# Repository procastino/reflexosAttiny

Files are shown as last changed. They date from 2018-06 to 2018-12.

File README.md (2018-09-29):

# reflexosAttiny
What can you do with three leds and a button? This is a very unflexible development board, where you must stretch your imagination to take some utility out of it. It has an attiny, the pushbutton and three leds. I left one pin free and accesible, because I'm a twisted guy with some goodness inside.
The real point of this was learning to design a simple board with KiCad and give some use to a bunch of AtTinys that I had laying around. Now I think it has some interest, for the right kind of people...
## Board
Develped in Kicad 4 (I'll upgrade if I beat my determined lazyness), it is surely not correct from a technical point of view, but it seems to work well.
## BOM
* 1 x AtTiny 85 - 20PU
* 1 x pushbutton 6 mm
* 3 x leds 3 mm
* 3 x 470 ohm resistors (depending on the leds, may need different value)
* 1 x 10Kohm resistor
* 12 right angle male pin headers
* 1 x cr2032 battery holder
* 1 x switch SK12D07V-G3

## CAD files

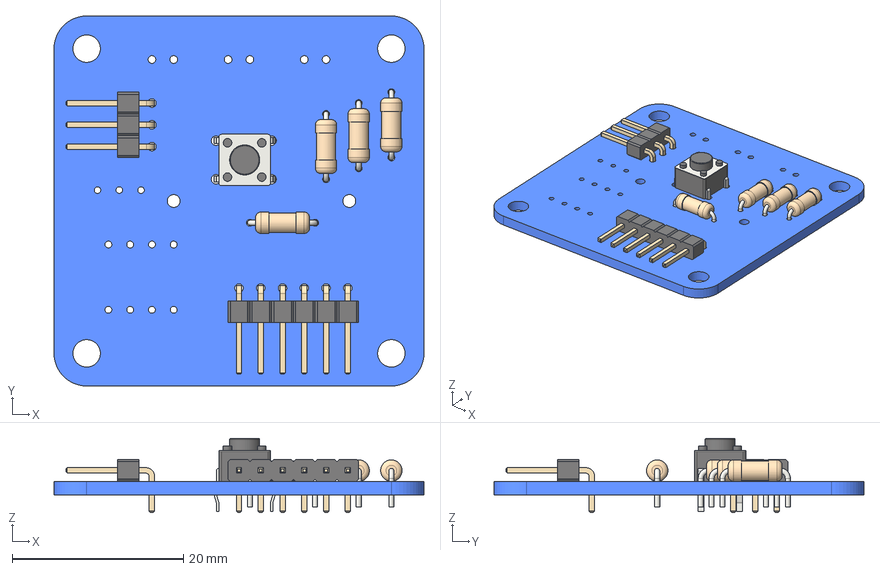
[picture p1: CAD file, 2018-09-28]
boardAttinyReflexos/attinyReflexos.step
43.2 x 43.2 x 8.64 mm
Pcb
Pin_Header_Angled_1x06_Pitch254mm_
Pin_Header_Angled_1x03_Pitch254mm_
R_Axial_DIN0207_L63mm_D25mm_P762mm_Horizontal_
R_Axial_DIN0207_L63mm_D25mm_P762mm_Horizontal_001
R_Axial_DIN0207_L63mm_D25mm_P762mm_Horizontal_002
R_Axial_DIN0207_L63mm_D25mm_P762mm_Horizontal_003
SW_PUSH_6mm_h5mm_

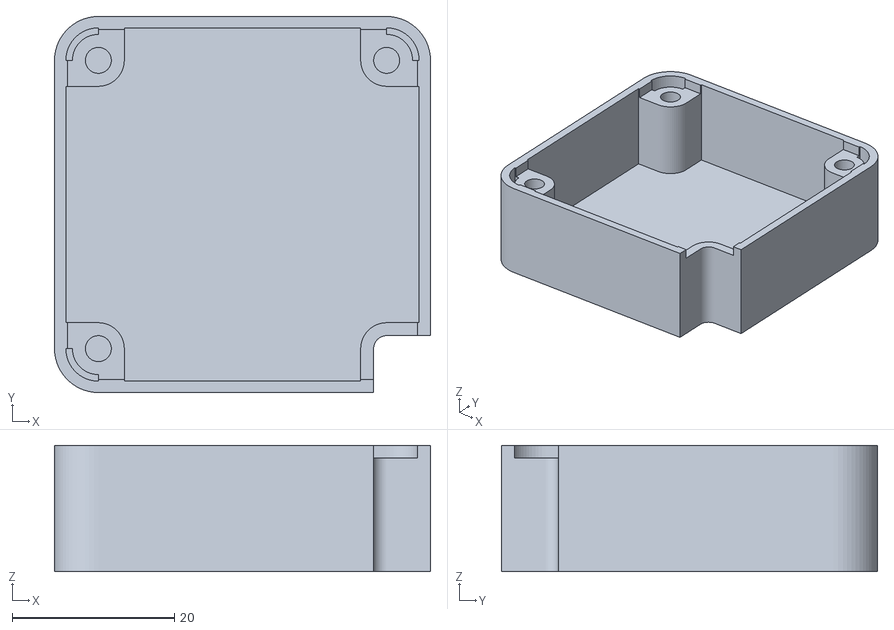
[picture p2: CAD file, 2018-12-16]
bottom.stl
46.4 x 46.4 x 15.6

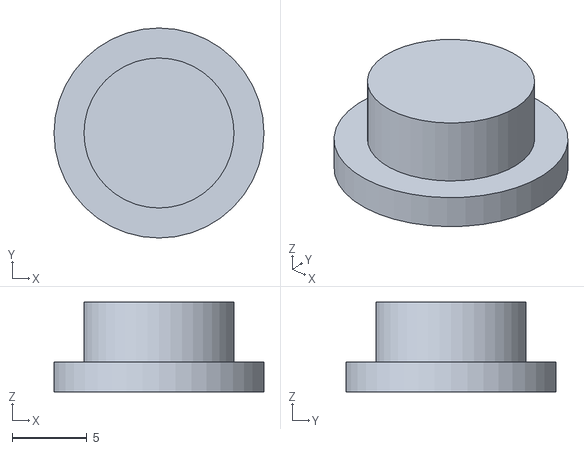
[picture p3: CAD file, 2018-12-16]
button2_6.stl
14.0 x 14.0 x 6.00

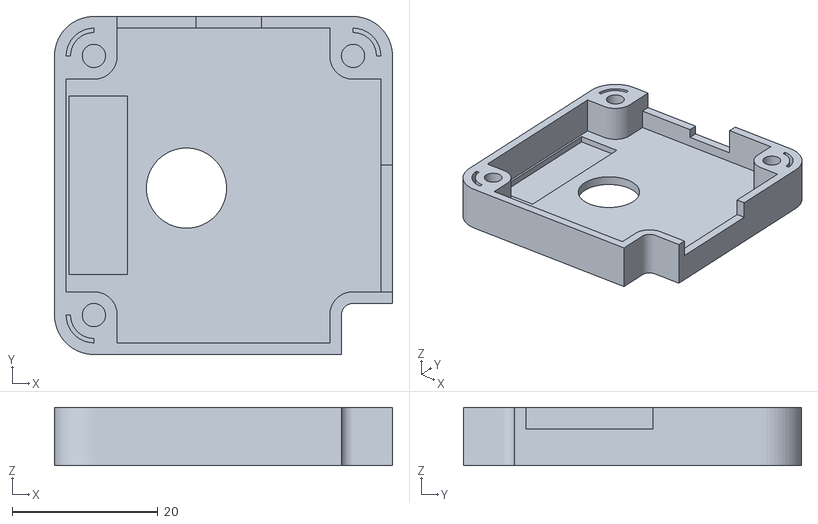
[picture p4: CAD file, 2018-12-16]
superior.stl
46.4 x 46.4 x 8.00

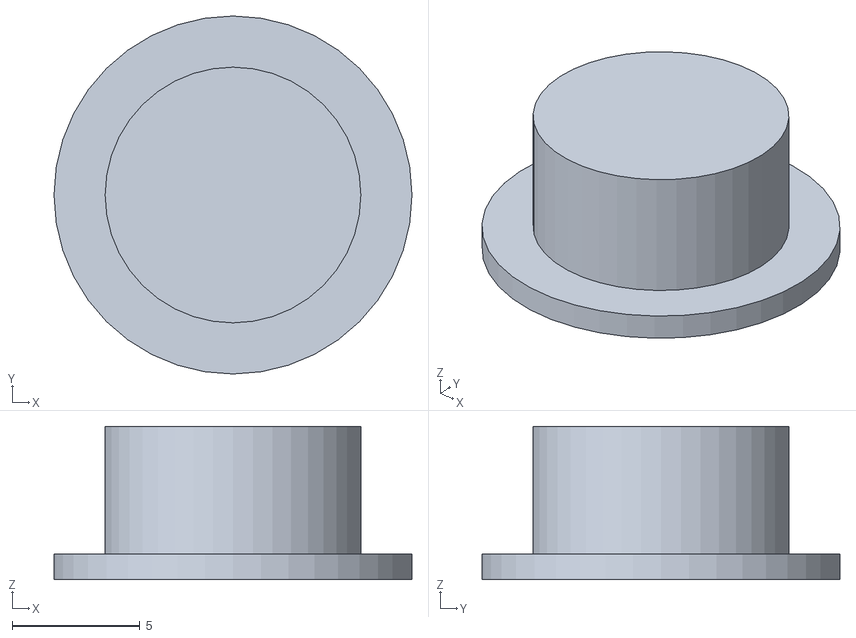
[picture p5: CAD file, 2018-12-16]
button1_6.stl
14.0 x 14.0 x 6.00

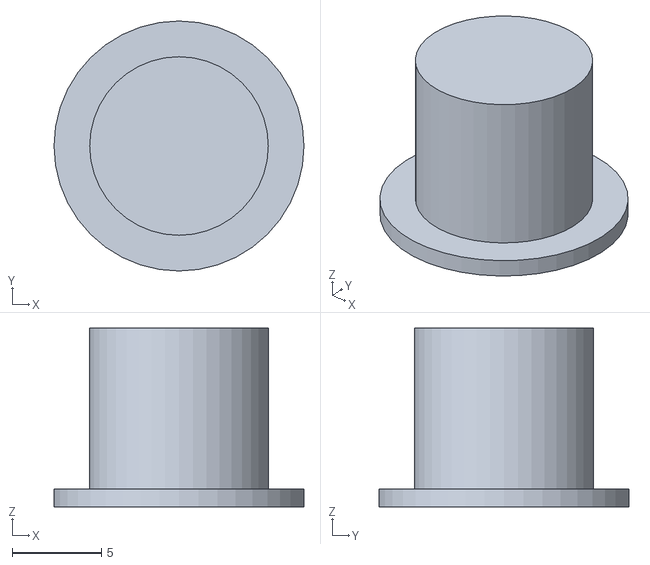
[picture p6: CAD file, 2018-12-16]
button1_10.stl
14.0 x 14.0 x 10.0

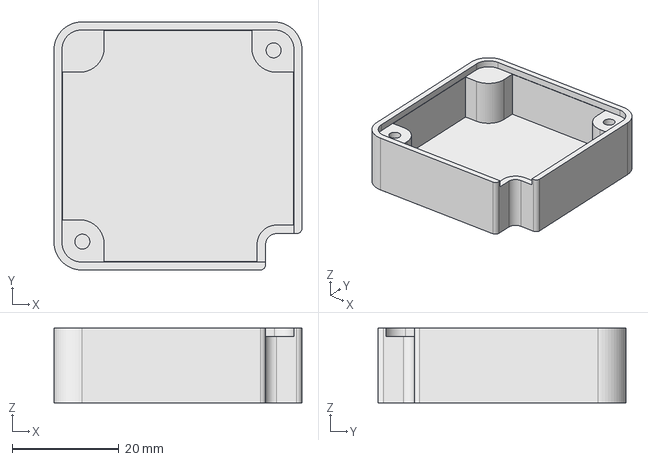
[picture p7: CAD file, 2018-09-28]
caixaPrimitivasSuperior.fcstd
46.4 x 46.4 x 14.0 mm

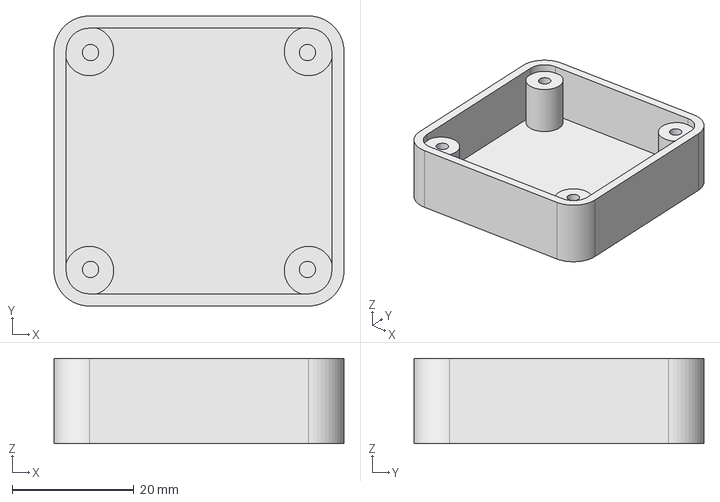
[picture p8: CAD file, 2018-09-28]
caixa.fcstd
47.6 x 47.6 x 14.0 mm

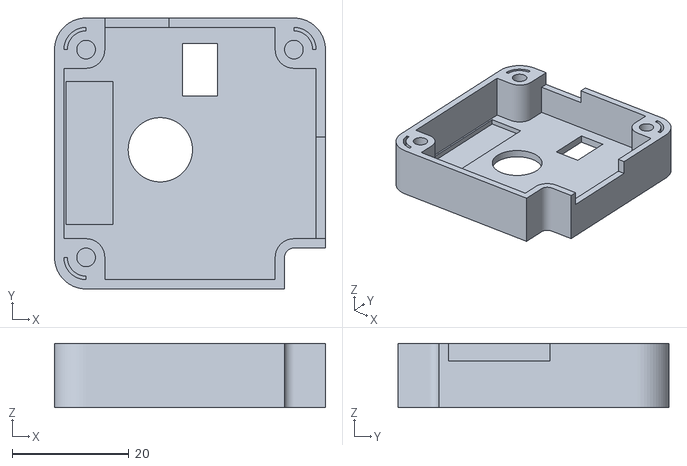
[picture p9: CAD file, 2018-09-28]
tapaSuperior.stl
46.4 x 46.4 x 11.0

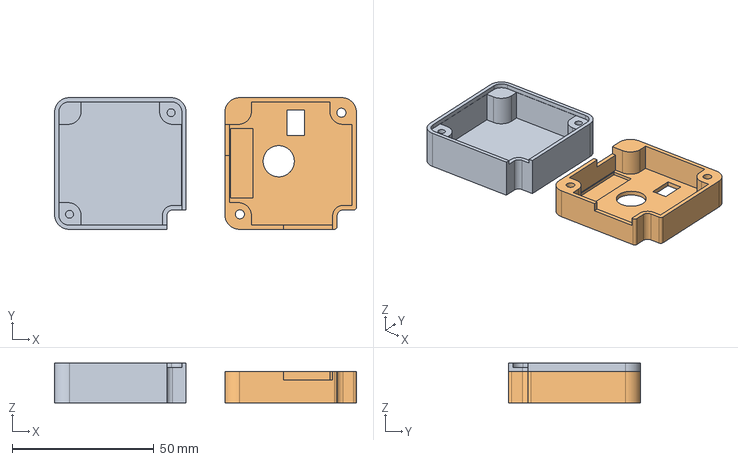
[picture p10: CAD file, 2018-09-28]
caixaPrimitivas.fcstd
106.4 x 46.4 x 14.0 mm
superior

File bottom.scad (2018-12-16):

$fn=60;
//distance between the holes of the pcb
holeDistance=35.56;
//tolerance for PCB carve, since the PDB doesn't fit well (quite a dirty fix)
tolerancePcb=0.2;
//thickness of the walls
thickness=1.6;
//distance between hole centers and pcb edge
holeToPcb=3.81;
//distance between hole centers and wall exterior
holeToExt=holeToPcb+thickness;
//radius of PCB holes
holeRadius=1.6;
//height of the whole bottom, from floor to top
height=14+thickness;

module exterior(){
    difference(){
        hull(){
        translate([holeToExt,holeToExt,0]) cylinder(r=holeToExt,h=height);
        translate([holeToExt,holeToExt+holeDistance,0]) cylinder(r=holeToExt,h=height);
        translate([holeToExt+holeDistance,holeToExt,0]) cylinder(r=holeToExt,h=height);
        translate([holeToExt+holeDistance,holeToExt+holeDistance,0]) cylinder(r=holeToExt,h=height);
        }
        translate ([holeToExt+holeDistance,holeToExt,0]) cornerCarve();
    }
}
module carve(){
    difference(){
  hull(){
    translate([holeToExt,holeToExt,0]) cylinder(r=holeToPcb+tolerancePcb,h=height);
   translate([holeToExt,holeToExt+holeDistance,0]) cylinder(r=holeToPcb+tolerancePcb,h=height);
   translate([holeToExt+holeDistance,holeToExt,0]) cylinder(r=holeToPcb+tolerancePcb,h=height);
   translate([holeToExt+holeDistance,holeToExt+holeDistance,0]) cylinder(r=holeToPcb+tolerancePcb,h=height);
    }
    translate ([holeToExt+holeDistance,holeToExt,0]) cornerCarveInt();
    }
}

//carving the pcb hole   
module pcbCarve(){
    hull(){
    translate([holeToExt,holeToExt,0]) cylinder(r=holeToPcb,h=height);
   translate([holeToExt,holeToExt+holeDistance,0]) cylinder(r=holeToPcb,h=height);
   translate([holeToExt+holeDistance,holeToExt,0]) cylinder(r=holeToPcb,h=height);
   translate([holeToExt+holeDistance,holeToExt+holeDistance,0]) cylinder(r=holeToPcb,h=height);
    }
  }
  
module support(){
difference(){
    union(){
        cylinder(r=holeRadius+thickness,h=height);
        translate([-holeToExt,0,0]) cube([holeToExt,holeRadius+thickness,height]);
         translate([0,-holeToExt,0]) cube([holeRadius+thickness,holeToExt,height]);
    }
translate([0,0,thickness])cylinder(r=holeRadius,h=height);
}
}
module cornerCarve() {
cylinder(r=holeRadius,h=height);
cube([holeToExt,holeRadius,height]);
translate([-holeRadius,-holeToExt-1,0]) cube([holeRadius+holeToExt,holeToExt+1,height]);
}
module cornerCarveInt() {
cylinder(r=holeRadius+thickness,h=height);
cube([holeToExt+thickness,holeRadius+thickness,height]);
translate([-(holeRadius+thickness),-(holeToExt+thickness+1),0]) cube([holeRadius+holeToExt+thickness,holeToExt+thickness+1,height]);
}
//we make the lid in here
difference(){
union(){
difference() {
    exterior();
    translate ([0,0,thickness]) carve();
    }
    
    translate([holeToExt,holeToExt,0]) support();
    translate([holeToExt,holeToExt+holeDistance,0])  rotate([0,0,-90]) support();
    translate([holeToExt+holeDistance,holeToExt+holeDistance,0]) rotate([0,0,180]) support();
}
 translate ([0,0,height-thickness]) pcbCarve();
}

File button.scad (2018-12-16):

$fn=40;
cylinder(r=7,h=1);
cylinder(r=5,h=10);

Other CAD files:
caixaInferiorPrimitivas.stl
caixaInferior.stl
superior.scad
boardAttinyReflexos/attinyReflexos.FCStd

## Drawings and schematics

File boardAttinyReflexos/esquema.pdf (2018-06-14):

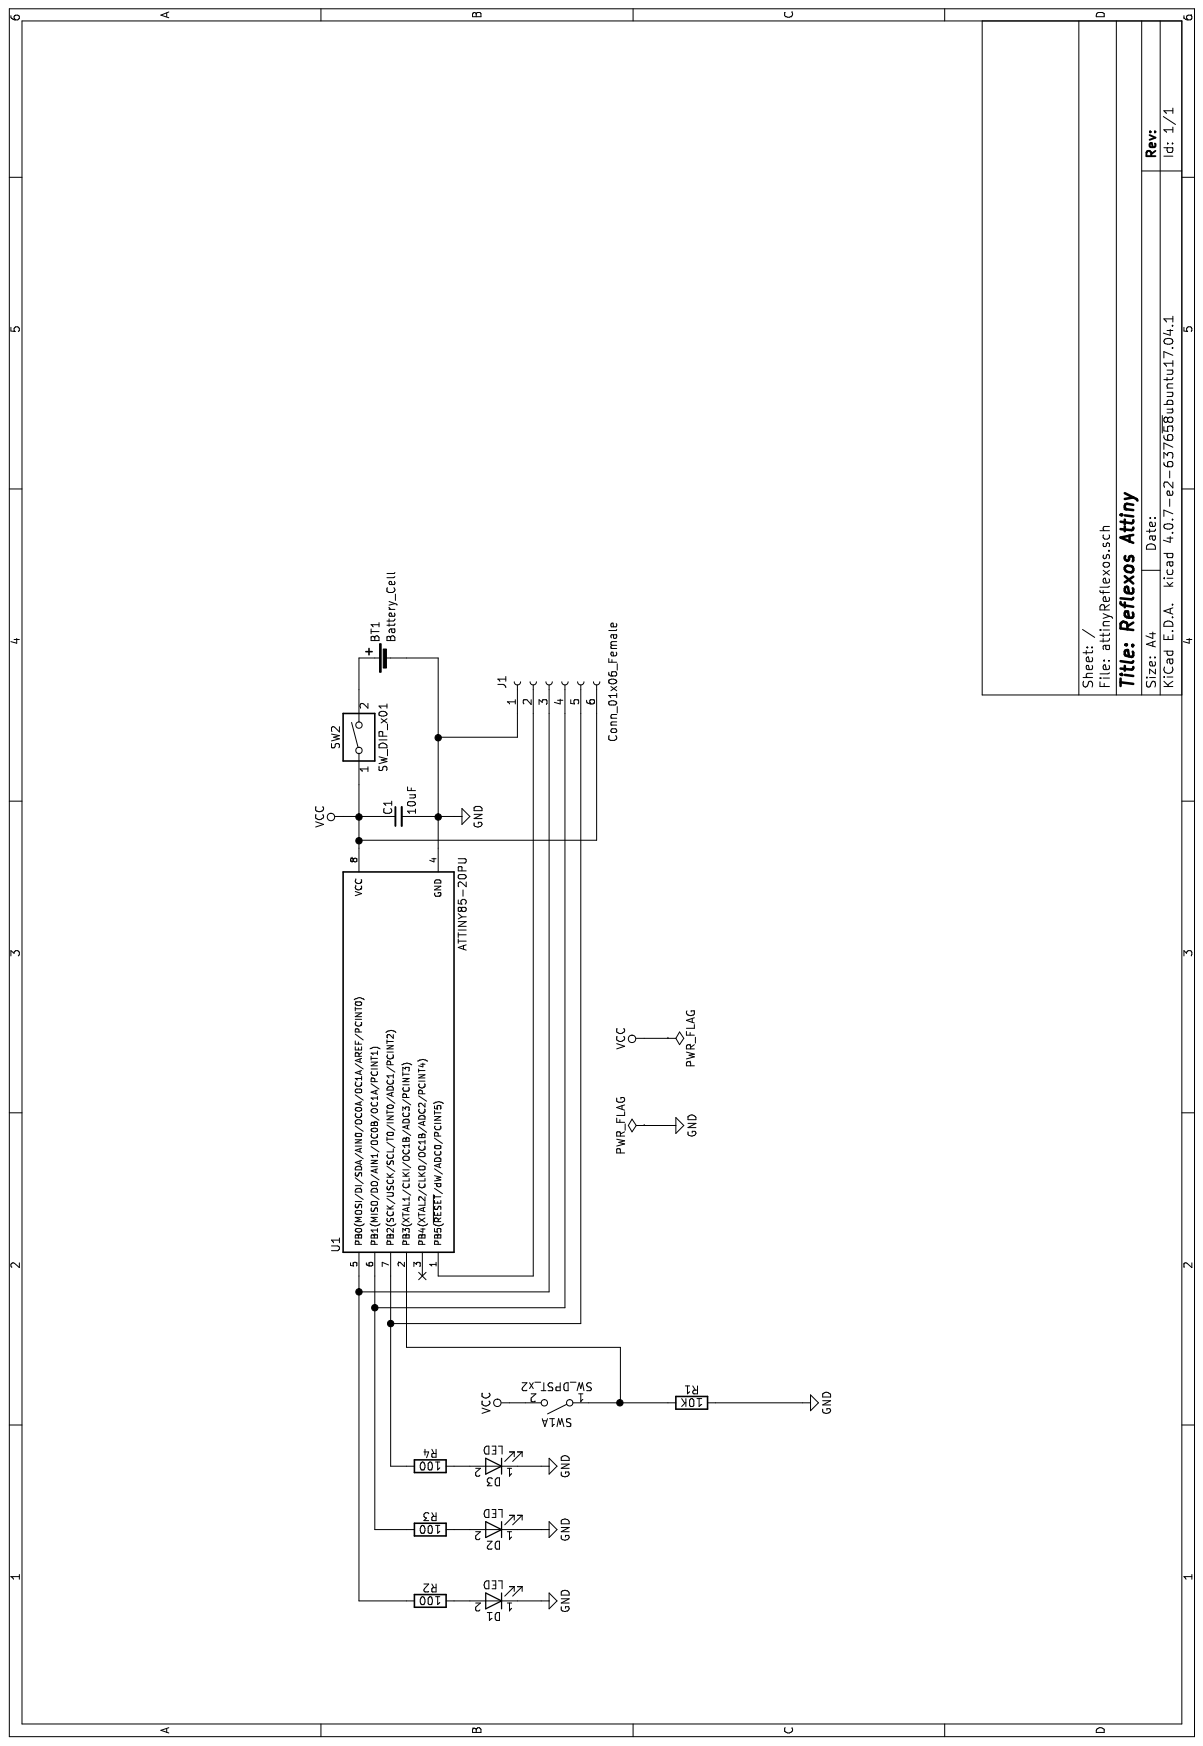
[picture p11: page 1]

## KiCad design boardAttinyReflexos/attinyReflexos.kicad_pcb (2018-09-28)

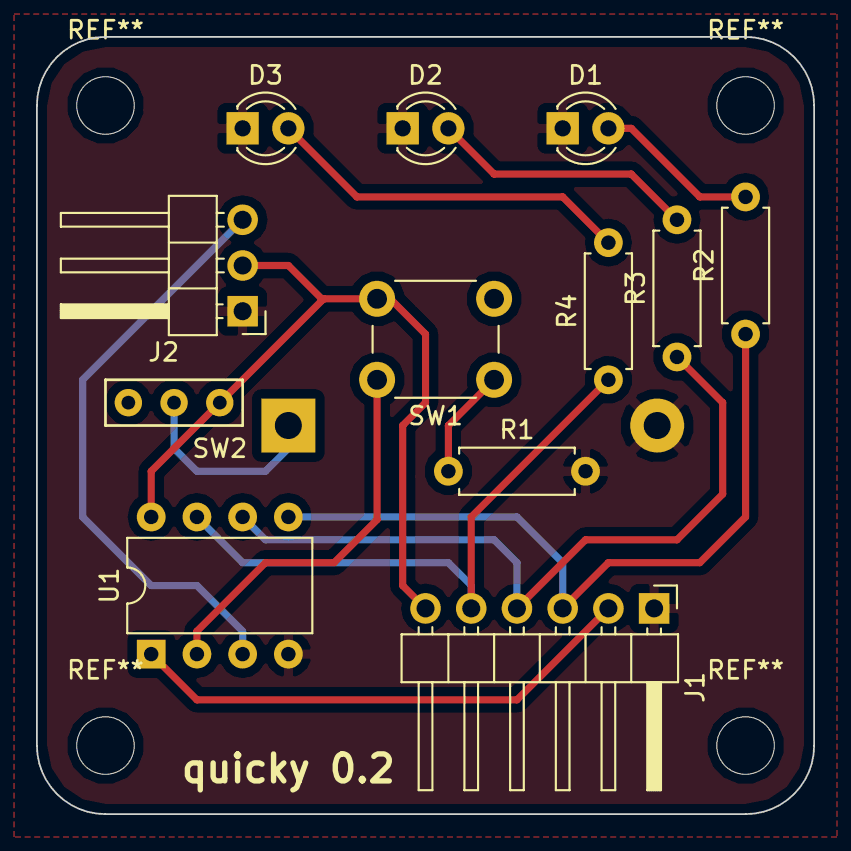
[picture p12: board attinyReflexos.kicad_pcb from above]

Board: 2 copper layers, 43.2 x 43.2 mm, 13 parts (1 on the bottom side), 12 nets.

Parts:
BT1: Battery_Cell; Keystone_103_1x20mm-CoinCell
D1, D2, D3: LED; LED_D3.0mm
J1: Conn_01x06_Female; Pin_Header_Angled_1x06_Pitch2.54mm
J2: Conn_01x03_Female; Pin_Header_Angled_1x03_Pitch2.54mm
R1: 10K; R_Axial_DIN0207_L6.3mm_D2.5mm_P7.62mm_Horizontal
R2, R3, R4: 100; R_Axial_DIN0207_L6.3mm_D2.5mm_P7.62mm_Horizontal
SW1: SW_DPST_x2; SW_PUSH_6mm_H5mm
SW2: SW_DIP_x01; switchSlide
U1: ATTINY85-20PU; DIP-8_W7.62mm

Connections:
GND: BT1.2, D1.1, D2.1, D3.1, J1.1, J2.1, R1.2, U1.4
unnamed: BT1.1, SW2.2
unnamed: D1.2, R2.2
unnamed: D2.2, R3.2
unnamed: D3.2, R4.2
unnamed: J1.2, U1.1
unnamed: J1.3, R2.1, U1.5
unnamed: J1.4, R3.1, U1.6
unnamed: J1.5, R4.1, U1.7
unnamed: J2.3, U1.3
unnamed: R1.1, SW1.1, U1.2
VCC: J1.6, J2.2, SW1.2, SW2.1, U1.8

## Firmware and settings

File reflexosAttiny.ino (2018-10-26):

/*Xogo de reflexos, debes pulsar o botón cando se acenda o led do medio, se acertas subirás un nivel, se fallas perderás.*/

//definimos os pines onde van os leds, boton e buzzer
//version 0.2    
    int led1=2;
    int led2=1;
    int led3=0;
    int boton=3;

//// version 0.1    
//    int led1=1;
//    int led2=2;
//    int led3=3;
//    int boton=0;

//// arduino UNO   
//    int led1=8;
//    int led2=9;
//    int led3=10;
//    int boton=7;

//definimos as variables que necesitaremos para ter conta do tempo
    long tempoActual = 0;
//este seria o tempo de espera co que arranca o xogo
    long tempoAceso = 1200;
//este sera o factor de aceleracion polo que se multiplica o tempo de espera. 
//Canto mais baixo, mais acelera en cada nivel.
    float aceleracion = 0.9;

//definimos unha variable que almacenara o numero aleatorio que fai que
//se acenda un led determinado
    long numeroChou;

//led2Aceso nos indicara se o led numero 2, ao que temos que reaccionar
// estara ou non aceso. Por iso e "boolean" que so admite "true" o "false"
    boolean led2Aceso;

//estas duas variables nos serviran para ter conta das pulsacions do boton
    int botonAntes = 0;
    int botonAgora;

//esta variable nos servira para ter conta do nivel ao que chegamos
    int nivel = 0;
//esta variable sirve para amosar o nivel ao que chegamos, sendo o resto de %7
    int resto; //aqui para facela accesible a funcion amosaresto()

void setup() {
    //definimos os pines dos leds como saidas e o boton coma entrada
      pinMode(led1,OUTPUT);
      pinMode(led2,OUTPUT);
      pinMode(led3,OUTPUT);
      pinMode(boton,INPUT);
      //creamos unha semente a partir da lectura do pin desconectado para conseguir verdadeira aleatoriedade
      randomSeed(analogRead(A2));
      //conta atras antes de comezar
      secuenciaInicio();
     }

void loop(){
    //chamamos a funcion de encendido    
       acendeLeds();
   //leremos o boton e comparamos
       compara();   
    }

//funcion de encendido de Leds
  void acendeLeds() {
    //comproba se xa pasou o intervalo de tempo que definimos como tempoAceso
      if ((millis()-tempoActual)>tempoAceso){
        //Apagamos todos os leds un intre para evitar que pareza que non cambian se se repite o mesmo led
        apagaTodos();
        delay(20);
        
        //Escollemos un numero ao chou que pode ser 1,2 ou 3
        numeroChou=random(1,4);
        
        //segundo o numero que saia, encendemos un led ou outro e definimos se led2Aceso
        //e "true" o "false"
        digitalWrite (led1,numeroChou == 1);
        digitalWrite (led2,numeroChou == 2);
        digitalWrite (led3,numeroChou == 3);
        led2Aceso = (numeroChou == 2);
        //con esta liña "reseteamos" o tempoActual
         tempoActual=millis();
       }
    }

//funcion que le o boton e comproba se acertamos
void compara() {
  //Leo o boton
  botonAgora = digitalRead(boton);
  
  //Comparo se o boton cambiou de estado
  //Se cambiou de estado e, ademais, vale 1
  if (botonAgora != botonAntes && botonAgora){
    //Se o que estaba aceso non era o led 2 perdes e amosamos os puntos
    if (!led2Aceso) {
      amosaPuntos();
      }
    //en caso contrario sera que o fixen ben e chamo a funcion "acertas()"
      else {
        acertas();
        }
    }
  //Se non cambiou de estado, transformo o estado actual en estado anterior
    else {
      botonAntes = botonAgora;
      }
    }
 
//Funcion en caso de acertar
    void acertas() {
        //Gardo o estado en que estou coma estado anterior
            botonAntes = digitalRead(boton);     
        //subo un nivel
            nivel++;
        //Encendo os tres leds durante 0,6 seg e os apago durante 0,4
            acendeTodos();
            delay(600);
            apagaTodos();
            delay(400);
          //multiplico o tempo de transicion polo factor de aceleracion
            tempoAceso = tempoAceso*aceleracion;
       }

//Funcion para amosar a puntuacion con flashes dos leds
/* A puntuacion amosarase con flashes en binario, dando un flash 
 *  dos tres leds (111) por cada 7 niveis 
 *  acadados mais o resto. Repetirase ate premer de novo o boton
 */
  void amosaPuntos() {
    //despois dun retardo pequeno, reseteamos valores
    delay(300);
    tempoAceso=1200;
    botonAntes=0;
    //esta variable almacena o numero de setes flasheados
    int setesPasados=0;
    //almacena o tempo que duran as pulsacions dos puntos
    int tempoPuntos;
    //o numero de pulsos de 111 sera igual ao nivel acadado entre 7
    int setes= nivel/7;
    //o resto, unha vez pulsados os setes, sera o modulo de nivel entre 7
    resto=nivel%7;
    
    //comezamos o contador de tempo
    int tempo=millis();
    //variable para o bucle
    boolean parar = false;
    /*===========desde aqui==========
     * ===========================
     * ===================
     * =================
     */
    while (!parar){
      //lemos boton
      botonAgora=digitalRead(boton);
      if (botonAgora != botonAntes && botonAgora==1){
        secuenciaInicio();
        parar = true;
       }
        else {
          int tempoFlash=millis()-tempo;
         // isto e para diferenciar o primeiro sete, creo que quedaria mellor cunha pausa no canto de mais tempo aceso, pero non dou
          if (setesPasados==0){
            tempoPuntos=1800;
          }
          else {
            tempoPuntos=800;
          }
          
          if (tempoFlash<=tempoPuntos && setesPasados<setes){
              acendeTodos();
              }
          if (tempoFlash<=tempoPuntos && setesPasados==setes){
                acendeResto(); 
              }
  
              
          if (tempoFlash>tempoPuntos && tempoFlash<=tempoPuntos+600){
            apagaTodos();
            }
            
          if (tempoFlash>tempoPuntos+600) {
            tempo=millis();
            setesPasados++;
            if (setesPasados>setes){
              setesPasados = 0;
              }
            }
        }
      }
      nivel=0;
    }

// funcion para acender todos os leds
void acendeTodos(){
  digitalWrite (led1,HIGH);
  digitalWrite (led2,HIGH);
  digitalWrite (led3,HIGH);
  
}

//funcion para apagar todos os leds
void apagaTodos() {
  digitalWrite (led1,LOW);
  digitalWrite (led2,LOW);
  digitalWrite (led3,LOW);
}

//funcion que acende os leds correspondentes do resto
void acendeResto() {
   digitalWrite(led3, bitRead(resto, 0)); 
   digitalWrite(led2, bitRead(resto, 1));
   digitalWrite(led1, bitRead(resto, 2));          
}
    
void secuenciaInicio(){
        digitalWrite (led1,LOW);
        digitalWrite (led2,LOW);
        digitalWrite (led3,LOW);
        delay(400);
        digitalWrite (led1,HIGH);
        digitalWrite (led2,HIGH);
        digitalWrite (led3,HIGH);
        delay(400);
        digitalWrite (led1,LOW);
        digitalWrite (led2,HIGH);
        digitalWrite (led3,HIGH);
        delay(300);
        digitalWrite (led1,LOW);
        digitalWrite (led2,LOW);
        digitalWrite (led3,HIGH);
        delay(300);
        digitalWrite (led1,LOW);
        digitalWrite (led2,LOW);
        digitalWrite (led3,LOW);
        delay(500);
       }


    
////Funcion en caso de perder
//    void perdiches(){
//      digitalWrite(buzzer,HIGH);
//                delay(600);
//                digitalWrite(buzzer, LOW);
//        //Encendo e apago os tres leds durante 0,3 seg, cinco veces
//            for (int i=0;i<5;i++){
//                acendeTodos();
//                digitalWrite(buzzer,LOW);
//                delay(200);
//                apagaTodos();
//                digitalWrite(buzzer,HIGH);
//                delay(200);
//                }
//                delay(300);
//                digitalWrite(buzzer,LOW);
//                //reinicio o nivel no que comezo
//            nivel=0;
//        //reinicio a variable de tempo de transicion do led
//           tempoAceso=1200;
//       }

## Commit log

2018-05-23 board files added
    [attinyReflexos-B.Cu.gbr, attinyReflexos-B.Mask.gbr, attinyReflexos-B.SilkS.gbr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]
2018-05-23 gerber zip added
    [attinyReflexos-B.Cu.gbr, attinyReflexos-B.Mask.gbr, attinyReflexos-B.SilkS.gbr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]
2018-06-06 corrixido erro
    [attinyReflexos-B.Cu.gbr, attinyReflexos-B.Mask.gbr, attinyReflexos-B.SilkS.gbr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]
2018-06-13 ancho pistas e buratos
    [attinyReflexos.kicad_pcb]
2018-09-28 big updates
    [attinyReflexos-B.Cu.gbr, attinyReflexos-B.Mask.gbr, attinyReflexos-B.SilkS.gbr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]
2018-09-29 better readme
    [attinyReflexos-2018-09-29-17-01-31.sch, attinyReflexos.sch]
2018-12-16 caixa en openscad
    [attinyReflexos-B.Cu.gbr, attinyReflexos-B.Mask.gbr, attinyReflexos-B.SilkS.gbr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]

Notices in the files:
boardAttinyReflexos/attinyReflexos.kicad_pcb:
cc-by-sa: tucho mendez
